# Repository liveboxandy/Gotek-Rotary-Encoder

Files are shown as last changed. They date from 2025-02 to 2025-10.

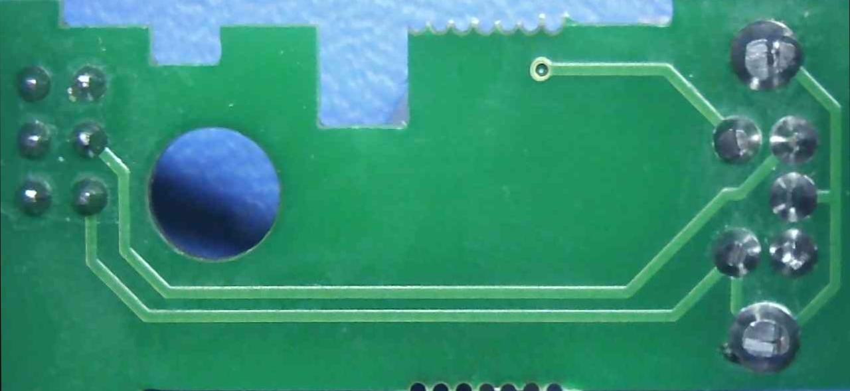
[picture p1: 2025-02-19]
Rotary Btm.jpg

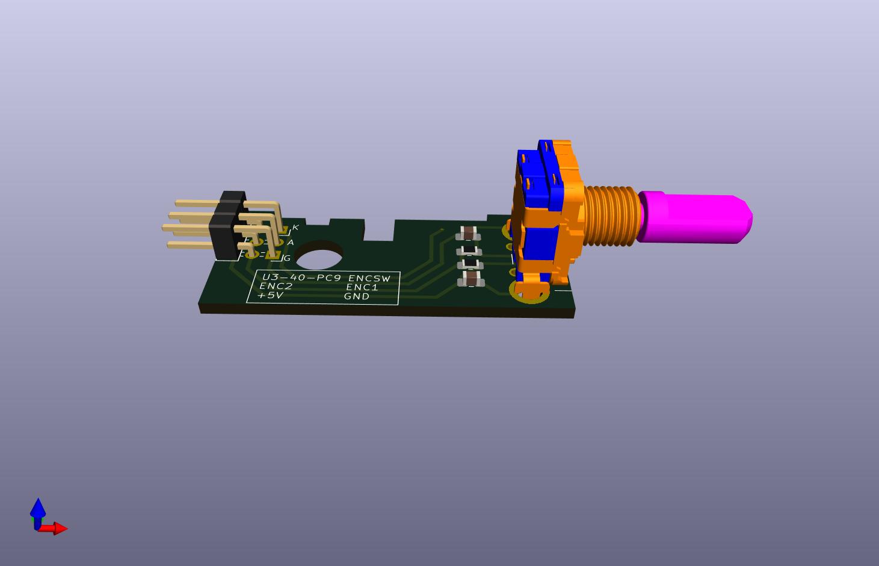
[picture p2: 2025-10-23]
Rotary Encoder.jpg

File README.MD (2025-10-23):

Initial schematic and gerbers for a Gotek Rotary Encoder PCB.

Used photographs and a multimeter.

Where possible I followed the original PCB routing but Kicad has some different rules for trace widths.

Updated for Kicad 9

Added ibom (bom/ibom.html) Not sure why given the component count.

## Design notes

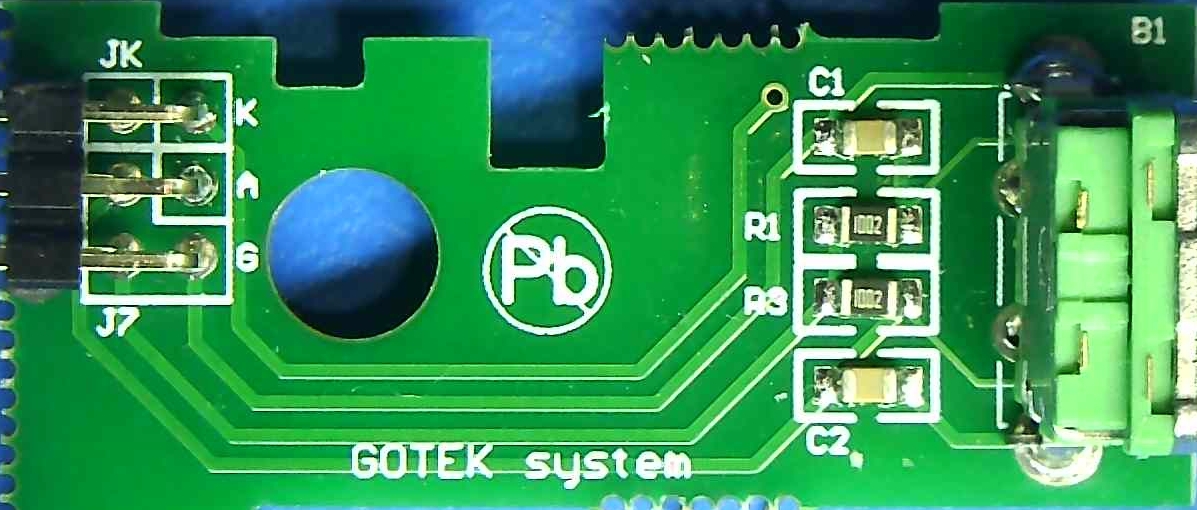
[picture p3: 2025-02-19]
Rotary Top.jpg

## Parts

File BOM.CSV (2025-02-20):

Reference | Value | Datasheet | Footprint | Qty | DNP
B1 | EC11B15242AE | https://www.farnell.com/datasheets/1837001.pdf?_gl=1*s3rpj4*_gcl_au*MTYzNzgwMTEwMS4xNzMwMTE1NDYx | Rotary:EC11B15242AE | 1
C1,C2 | 10nF | ~ | Capacitor_SMD:C_0805_2012Metric_Pad1.18x1.45mm_HandSolder | 2
J7 | Conn_02x02_Odd_Even | ~ | Connector_PinHeader_2.54mm:PinHeader_2x02_P2.54mm_Horizontal | 1
JK1 | Conn_02x01 | ~ | Connector_PinHeader_2.54mm:PinHeader_2x01_P2.54mm_Horizontal | 1
R1,R2 | 10K | ~ | Resistor_SMD:R_0805_2012Metric_Pad1.20x1.40mm_HandSolder | 2

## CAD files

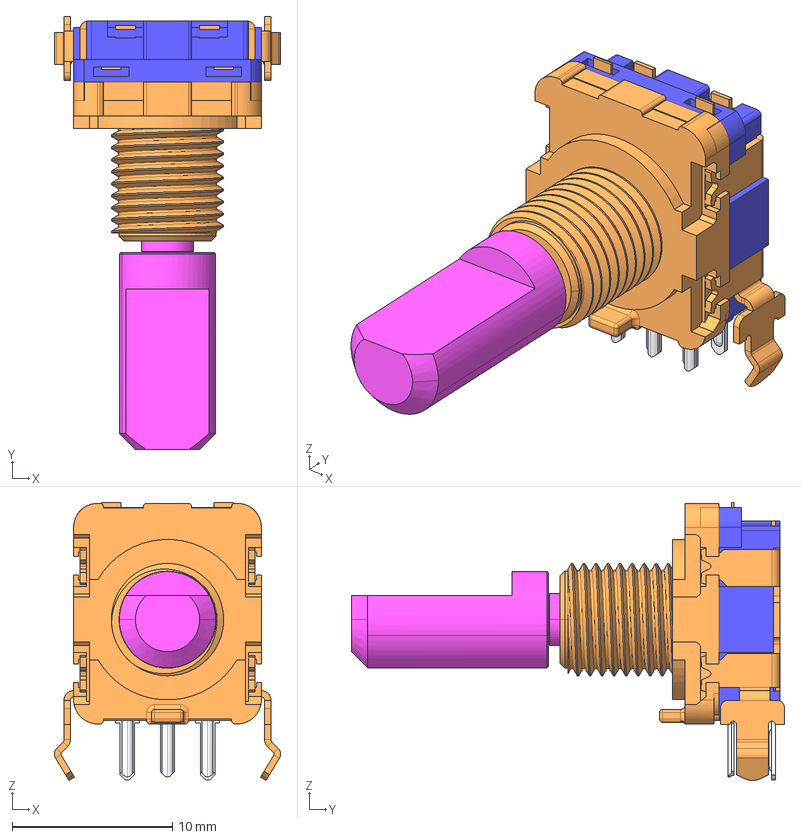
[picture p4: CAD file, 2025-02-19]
3D/EC11B15242AE.stp
14.1 x 27.0 x 17.3 mm

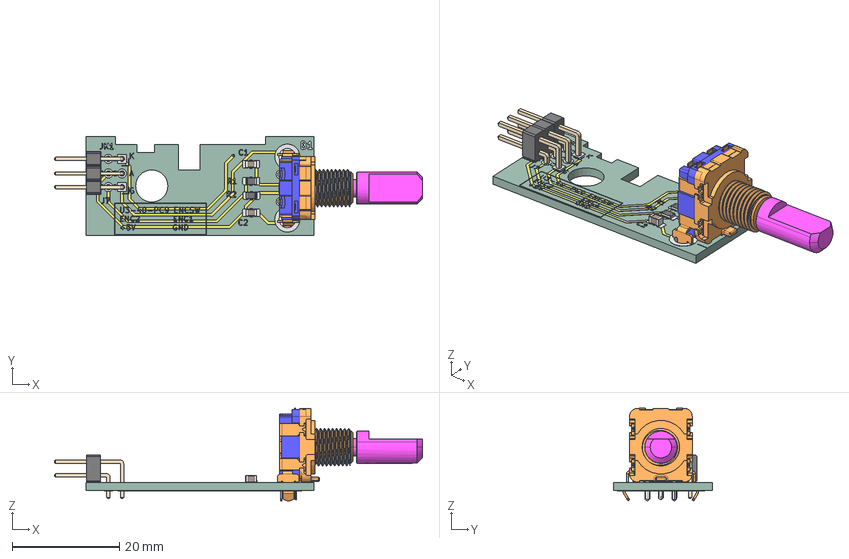
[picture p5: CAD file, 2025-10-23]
Rotary Encoder.step
68.6 x 18.5 x 17.3 mm
PinHeader_2x01_P2.54mm_Horizontal
PinHeader_2x02_P2.54mm_Horizontal
R_0805_2012Metric x 2
C_0805_2012Metric x 2
EC11B15242AE
Rotary Encoder_copper
Rotary Encoder_pad
Rotary Encoder_via
Rotary Encoder_silkscreen
Rotary Encoder_PCB

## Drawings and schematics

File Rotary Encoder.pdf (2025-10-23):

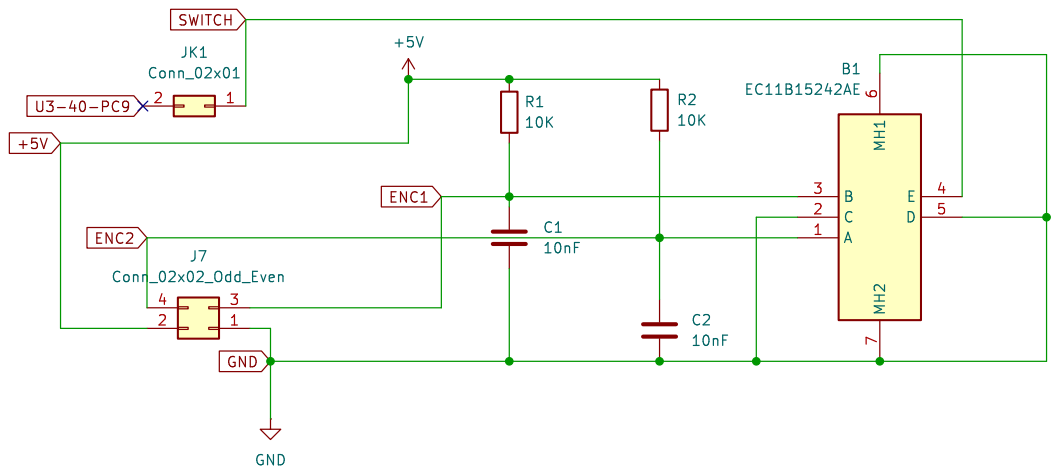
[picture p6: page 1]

Id: 1/1 Title: Gotek AT32F435 Rotary Encoder PCB

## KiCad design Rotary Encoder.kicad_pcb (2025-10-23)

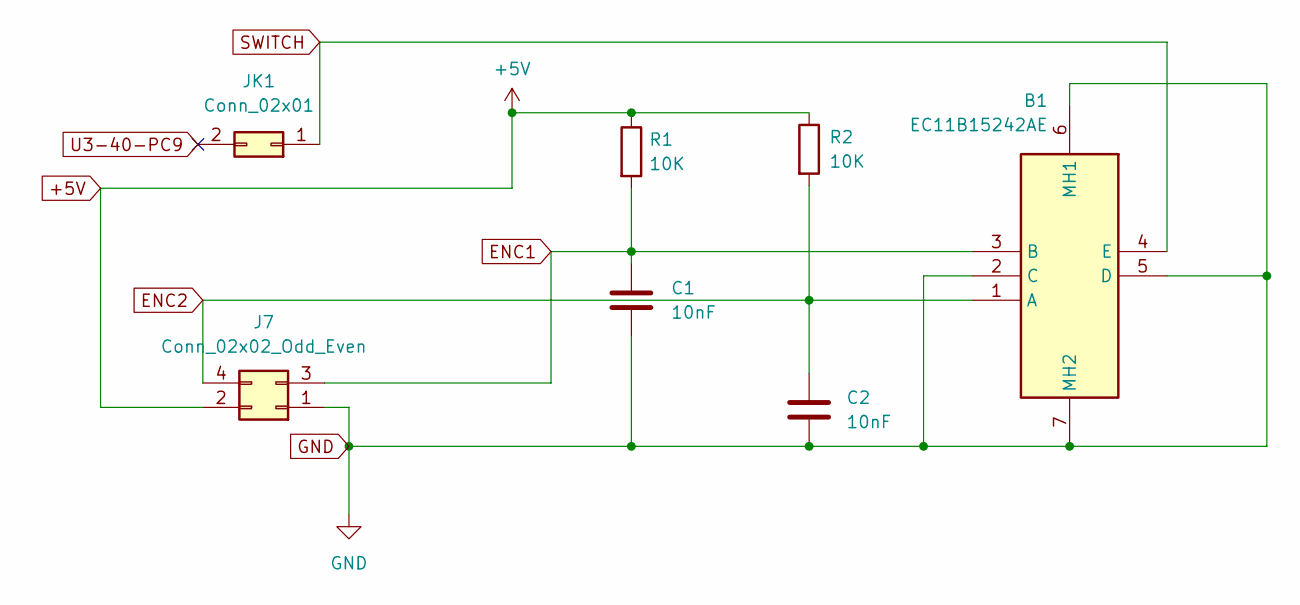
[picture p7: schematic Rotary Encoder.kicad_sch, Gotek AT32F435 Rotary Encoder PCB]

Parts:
B1: EC11B15242AE; Manufacturer_Part_Number EC11B15242AE; Mouser Part Number 688-EC11B15242AE
C1, C2: 10nF; C_0805_2012Metric_Pad1.18x1.45mm_HandSolder
J7: Conn_02x02_Odd_Even; PinHeader_2x02_P2.54mm_Horizontal
JK1: Conn_02x01; PinHeader_2x01_P2.54mm_Horizontal
R1, R2: 10K; R_0805_2012Metric_Pad1.20x1.40mm_HandSolder

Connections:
+5V: J7.2, R1.1, R2.1
ENC1: B1.3 (B), C1.1, J7.3, R1.2
ENC2: B1.1 (A), C2.1, J7.4, R2.2
GND: B1.2 (C), B1.5 (D), B1.6 (MH1), B1.7 (MH2), C1.2, C2.2, J7.1
SWITCH: B1.4 (E), JK1.1
U3-40-PC9: JK1.2

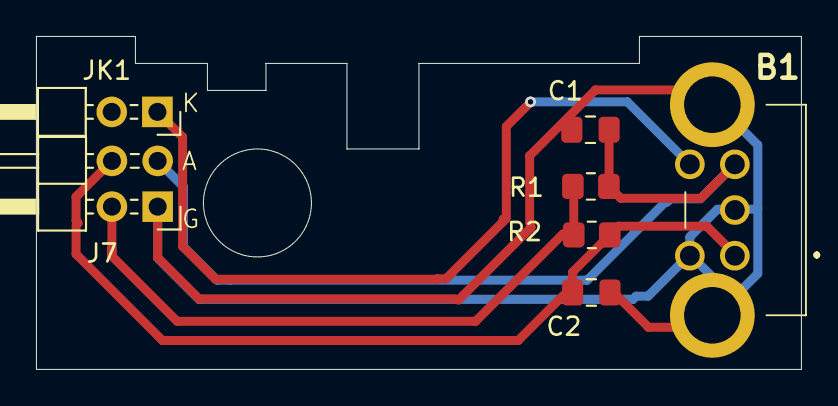
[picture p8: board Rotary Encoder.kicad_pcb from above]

Board: 2 copper layers, 42.5 x 18.5 mm, 7 parts (0 on the bottom side), 5 nets.

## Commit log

2025-02-19 Add files via upload
    Initial Release
    [EC11B15242AE.stp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]
2025-02-20 Add files via upload
    Added labels on schematic and connector pin descriptions to PCB
    [BOM.CSV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]
2025-10-23 Minor Changes
    Updated for Kicad 9
    Added ibom (bom/ibom.html)
    [Rotary Encoder-B_Cu.gbr, Rotary Encoder-B_Mask.gbr, Rotary Encoder-B_Paste.gbr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]
